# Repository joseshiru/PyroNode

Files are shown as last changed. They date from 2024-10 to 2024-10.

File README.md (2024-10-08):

# PyroNode

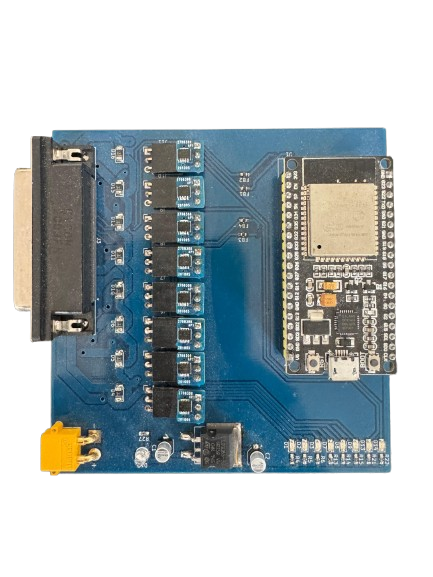
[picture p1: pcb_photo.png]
PCB Photo


**PyroNode** is an open-source ESP32-based control system designed to manage multiple outputs, monitor temperature, and provide robust control over external devices. Originally built for automotive applications as a cost-effective alternative to a PMU (Power Management Unit) or aftermarket ECU, PyroNode has proven its versatility and can be adapted for various other projects, such as home automation or even controlling a **coffee roaster**.

## Features

- **ESP32-based system**: Powerful microcontroller with Wi-Fi and Bluetooth capabilities.
- **8 MOSFET-controlled outputs**: Manage and control up to 8 high-power circuits.
- **Overload protection**: Ensures safety and reliability in high-power environments.
- **Temperature monitoring**: Supports 2 thermocouples via **MAX6675K** and other temperature sensors like **MAX31855EASA**.
- **Waterproof connectors**: Ideal for harsh environments such as automotive, outdoor, or industrial applications.
- **Optoisolated inputs**: Protects the system from electrical noise and interference.
- **Modular MOSFET satellites**: Easy expansion and replacement of MOSFET modules.
- **Flexible usage**: Designed initially for automotive use but adaptable to many applications, including industrial controls, environmental monitoring, or DIY home projects.

## Applications

While PyroNode was initially created for controlling circuits in an automotive environment (like a PMU without the expense of aftermarket systems), it can be utilized in a wide range of other scenarios:

- **Automotive**: Act as a PMU to control different car subsystems.
- **Home automation**: Manage lighting, HVAC, or any other electronic devices.
- **Coffee roasting**: Use the temperature sensors and output controls to monitor and adjust a coffee roaster in real-time.
- **Industrial automation**: Control machines and monitor temperature in industrial settings.
- **Smart gardening**: Automate watering systems and monitor environmental conditions.

## Project Breakdown

### Hardware Overview
- **MOSFET Modules**: Utilize **PSMN013-30MLC MOSFETs** for high-efficiency switching and control of the 8 output channels.
- **Power Supply**: Uses an **LD1085D2T33 voltage regulator** to provide a stable 3.3V power supply.
- **Temperature Monitoring**: Equipped with **2 thermocouples via MAX6675K** for accurate temperature measurements, expandable with additional sensors like the **MAX31855EASA**.
- **Waterproof Connectors**: For safe usage in outdoor or automotive applications.
- **Optoisolation**: Provides electrical isolation to protect the ESP32 from spikes or noise in the connected circuits.
- **Modular Design**: MOSFET satellite modules can be easily expanded or swapped for different configurations.

### Software Overview

The software is built using the **Arduino IDE** for the ESP32 platform. A basic example of controlling the MOSFETs is included in the `main.cpp` file. The example alternates turning on and off the 8 MOSFET outputs with a delay of 1 second.

```cpp
#include <Arduino.h>

int MOSFET0_PIN = 13;
int MOSFET1_PIN = 14;
int MOSFET2_PIN = 27;
int MOSFET3_PIN = 26;
int MOSFET4_PIN = 25;
int MOSFET5_PIN = 21;
int MOSFET6_PIN = 22;
int MOSFET7_PIN = 23;

void setup() {
  pinMode(MOSFET0_PIN, OUTPUT);
  pinMode(MOSFET1_PIN, OUTPUT);
  pinMode(MOSFET2_PIN, OUTPUT);
  pinMode(MOSFET3_PIN, OUTPUT);
  pinMode(MOSFET4_PIN, OUTPUT);
  pinMode(MOSFET5_PIN, OUTPUT);
  pinMode(MOSFET6_PIN, OUTPUT);
  pinMode(MOSFET7_PIN, OUTPUT);
}

void loop() {
  digitalWrite(MOSFET0_PIN, HIGH);
  digitalWrite(MOSFET1_PIN, HIGH);
  digitalWrite(MOSFET2_PIN, HIGH);
  digitalWrite(MOSFET3_PIN, HIGH);
  digitalWrite(MOSFET4_PIN, HIGH);
  digitalWrite(MOSFET5_PIN, HIGH);
  digitalWrite(MOSFET6_PIN, HIGH);
  digitalWrite(MOSFET7_PIN, HIGH);
  delay(1000);  
  digitalWrite(MOSFET0_PIN, LOW);
  digitalWrite(MOSFET1_PIN, LOW);
  digitalWrite(MOSFET2_PIN, LOW);
  digitalWrite(MOSFET3_PIN, LOW);
  digitalWrite(MOSFET4_PIN, LOW);
  digitalWrite(MOSFET5_PIN, LOW);
  digitalWrite(MOSFET6_PIN, LOW);
  digitalWrite(MOSFET7_PIN, LOW);
  delay(1000); 
}

```
## License

This project is licensed under the **Creative Commons Attribution-NonCommercial 4.0 International (CC BY-NC 4.0)** license.

- **Free for personal and non-commercial use.**
- **Credits: Build by Jose Zuniga Marin.**
- **For commercial use, please contact hello@malecu.eu.**

You can read the full license [here](https://creativecommons.org/licenses/by-nc/4.0/).

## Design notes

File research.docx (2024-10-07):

- MOSFETS
  - MOSFETs are more durable than relays. The price is comparable. The galvanic isolation rises a question [?].
  - The replaceability – a custom connector can be produced. The advantage is robustness and the possibility to sell dedicated MOSFET modules. The disadvantage is the additional price of the connector (and the satellite PCB). There are TO-220 connectors available, but they are expensive and does not seem to be durable.
  - MOSFET-based solution is much smaller:
    - 3.4 x 3.4 x 0.9 mm (MOSFET) + 23.1 x 15.4 x 7.3 mm (MR30PW connector ~2.5€/pair) OR 13.9 x 7.9 x 2.5 mm (angled goldpin connector ~0.2€/pair)
    - 28.5 x 27.2 x 24.8 mm (relay) + 27 x 25 x 20 mm (connector)
  - Possible solution(s):
    - PSMN013-30MLC
  - Using 25A MOSFETS might be an overkill [?] a bit. 25A*8=200A -> PCB and the connector can be unable to handle it.
- The connector
  - 2 power pins
  - 4 (2*2) thermocouple pins
  - 16 (8*2) relays/MOSFETs pins
  - Separate powers pins [?] (XT-60)
  - The expected current [?] must be taken into account.
  - Possible solution(s):
    - DSUB-25 (female, horizontal) – 3A
    - ECU (aliexpress) – expensive, 3-4A
- Voltage regulator
  - LD1085D2T33R (3A, 4.9-30V, D2PAK)

THE RESULTS

- ESP32 + needed passive elements
- MOSFETs -> PSMN013-30MLC (https://eu.mouser.com/ProductDetail/Nexperia/PSMN013-30MLC115?qs=qs9S9JrzwyZJD0ZHBCqfpw==)

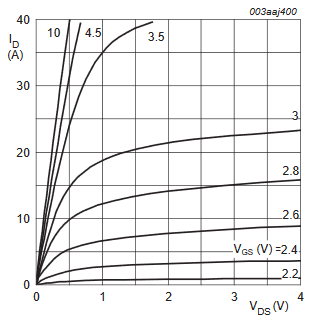
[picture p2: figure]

- Satellite boards for the MOSFETs
- LEDs to indicate MOSFETs states
- 8*2 MOSFET outputs + 2*2 thermocouple inputs
- The connector -> DSUB-25 (https://eu.mouser.com/ProductDetail/Amphenol-FCI/D25S23A4GV00LF?qs=V0y2QjpmBGS4pav1UJlQNQ%3D%3D) for signals + XT60PW-M (link (https://www.tme.eu/pl/details/xt60pw-m/zlacza-dc/amass/)) for power
- Voltage regulator -> LD1085D2T33R (link (https://www.tme.eu/pl/details/ld1085d2t33r/stabilizatory-napiecia-nieregulowane-ldo/stmicroelectronics/))

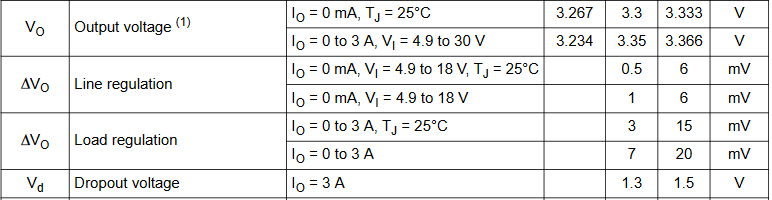
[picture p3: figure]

- Powering traces run parallelly on both PCB sides, unmasked, covered with solder

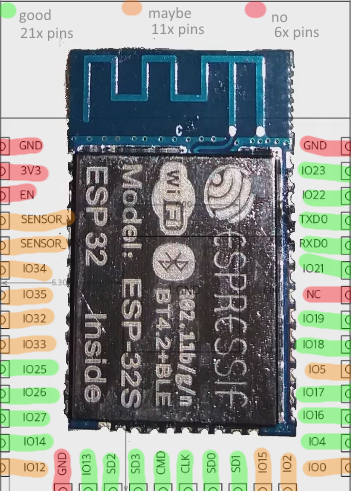
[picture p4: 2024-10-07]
image_2020_07_27T20_55_39_256Z.png

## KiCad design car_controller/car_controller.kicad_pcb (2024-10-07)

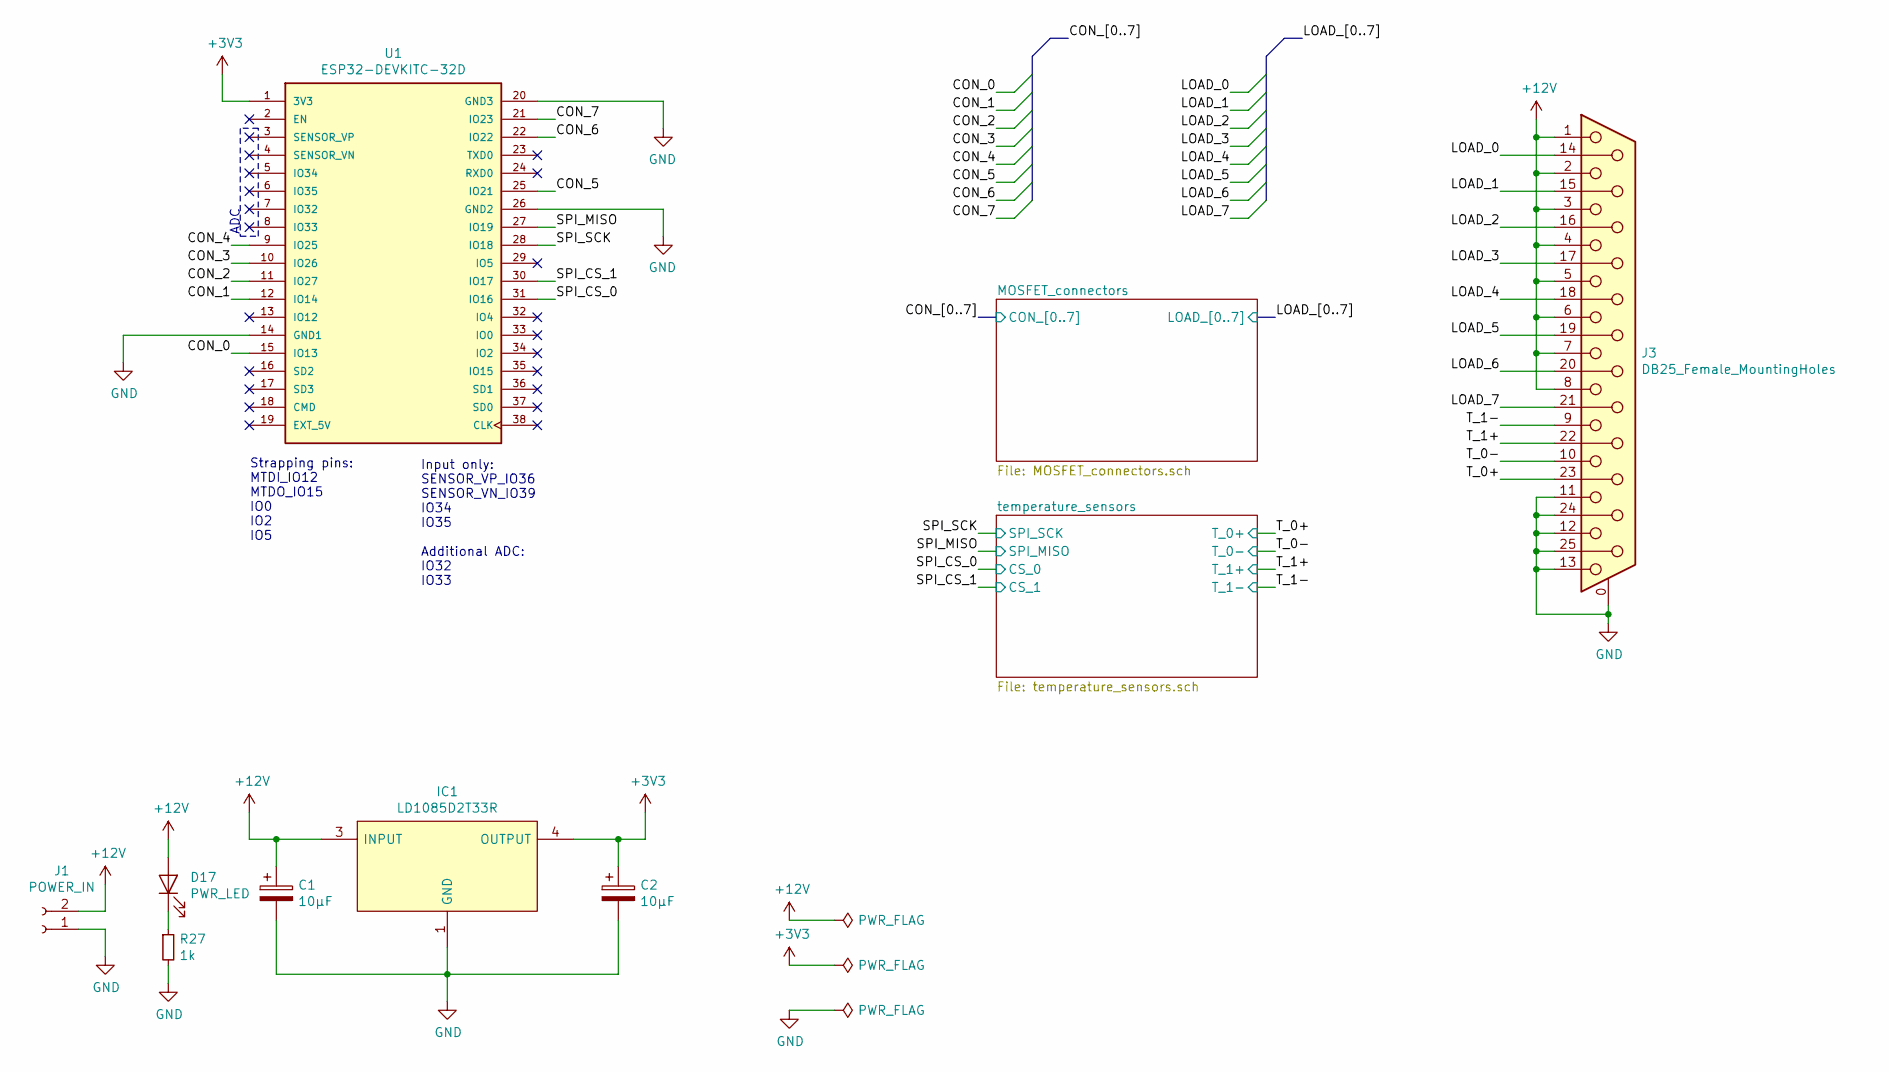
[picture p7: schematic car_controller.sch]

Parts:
C1, C2: 10µF; CP_Elec_4x5.3
D17: PWR_LED; LED_D3.0mm
IC1: LD1085D2T33R; Mouser Part Number 511-LD1085D2T33-TR
J1: POWER_IN; AMASS_XT30PW-M_1x02_P2.50mm_Horizontal
J3: DB25_Female_MountingHoles; DSUB-25_Female_Horizontal_P2.77x2.84mm_EdgePinOffset7.70mm_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
R27: 1k; R_0603_1608Metric_Pad1.05x0.95mm_HandSolder
U1: ESP32-DEVKITC-32D; MODULE_ESP32-DEVKITC-32D

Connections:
+3V3: C2.1, IC1.4 (OUTPUT), U1.1 (3V3); also elsewhere on the board
+12V: C1.1, D17.2 (A), IC1.3 (INPUT), J1.2, J3.1, J3.2, J3.3, J3.4, J3.5, J3.6, J3.7, J3.8; also elsewhere on the board
/CON_0: U1.15 (IO13); also elsewhere on the board
/CON_1: U1.12 (IO14); also elsewhere on the board
/CON_2: U1.11 (IO27); also elsewhere on the board
/CON_3: U1.10 (IO26); also elsewhere on the board
/CON_4: U1.9 (IO25); also elsewhere on the board
/CON_5: U1.25 (IO21); also elsewhere on the board
/CON_6: U1.22 (IO22); also elsewhere on the board
/CON_7: U1.21 (IO23); also elsewhere on the board
/LOAD_0: J3.14; also elsewhere on the board
/LOAD_1: J3.15; also elsewhere on the board
/LOAD_2: J3.16; also elsewhere on the board
/LOAD_3: J3.17; also elsewhere on the board
/LOAD_4: J3.18; also elsewhere on the board
/LOAD_5: J3.19; also elsewhere on the board
/LOAD_6: J3.20; also elsewhere on the board
/LOAD_7: J3.21; also elsewhere on the board
/SPI_CS_0: U1.31 (IO16); also elsewhere on the board
/SPI_CS_1: U1.30 (IO17); also elsewhere on the board
/SPI_MISO: U1.27 (IO19); also elsewhere on the board
/SPI_SCK: U1.28 (IO18); also elsewhere on the board
/T_0+: J3.23; also elsewhere on the board
/T_0-: J3.10; also elsewhere on the board
/T_1+: J3.22; also elsewhere on the board
/T_1-: J3.9; also elsewhere on the board
GND: C1.2, C2.2, IC1.1 (GND), J1.1, J3.0 (PAD), J3.11, J3.12, J3.13, J3.24, J3.25, R27.2, U1.14 (GND1), U1.20 (GND3), U1.26 (GND2); also elsewhere on the board
unnamed: D17.1 (K), R27.1

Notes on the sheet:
Strapping pins: MTDI_IO12 MTDO_IO15 IO0 IO2 IO5
Input only: SENSOR_VP_IO36 SENSOR_VN_IO39 IO34 IO35 Additional ADC: IO32 IO33
ADC

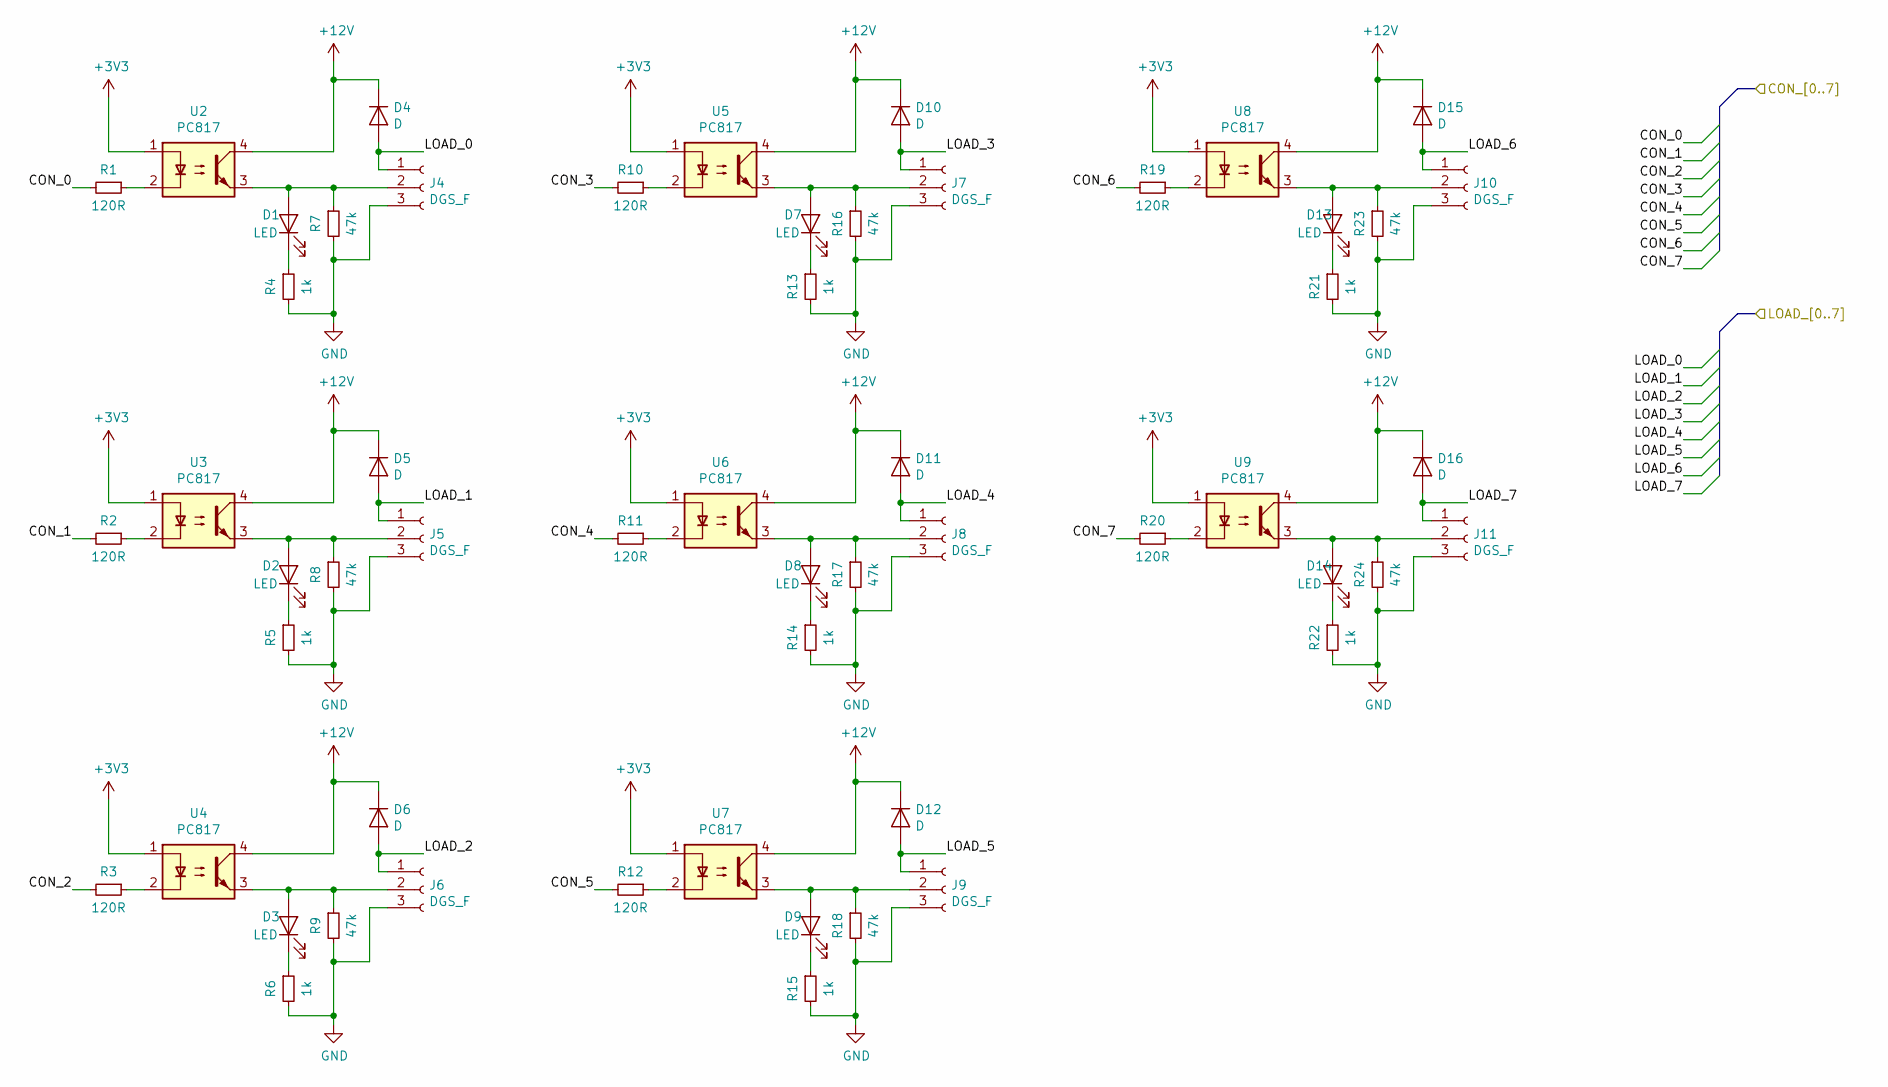
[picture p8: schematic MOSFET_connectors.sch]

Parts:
D1, D2, D3, D7, D8, D9, D13, D14: LED; LED_0805_2012Metric_Pad1.15x1.40mm_HandSolder
D4, D5, D6, D10, D11, D12, D15, D16: D; D_1206_3216Metric_Pad1.42x1.75mm_HandSolder
J4, J5, J6, J7, J8, J9, J10, J11: DGS_F; PinSocket_1x03_P2.54mm_Horizontal
R1, R2, R3, R10, R11, R12, R19, R20: 120R; R_0603_1608Metric_Pad1.05x0.95mm_HandSolder
R4, R5, R6, R13, R14, R15, R21, R22: 1k; R_0603_1608Metric_Pad1.05x0.95mm_HandSolder
R7, R8, R9, R16, R17, R18, R23, R24: 47k; R_0603_1608Metric_Pad1.05x0.95mm_HandSolder
U2, U3, U4, U5, U6, U7, U8, U9: PC817; OPTO-SMD4

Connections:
+3V3: U2.1, U3.1, U4.1, U5.1, U6.1, U7.1, U8.1, U9.1; also elsewhere on the board
+12V: D4.1 (K), D5.1 (K), D6.1 (K), D10.1 (K), D11.1 (K), D12.1 (K), D15.1 (K), D16.1 (K), U2.4, U3.4, U4.4, U5.4, U6.4, U7.4, U8.4, U9.4; also elsewhere on the board
/CON_0: R1.2; also elsewhere on the board
/CON_1: R2.2; also elsewhere on the board
/CON_2: R3.2; also elsewhere on the board
/CON_3: R10.2; also elsewhere on the board
/CON_4: R11.2; also elsewhere on the board
/CON_5: R12.2; also elsewhere on the board
/CON_6: R19.2; also elsewhere on the board
/CON_7: R20.2; also elsewhere on the board
/LOAD_0: D4.2 (A), J4.1; also elsewhere on the board
/LOAD_1: D5.2 (A), J5.1; also elsewhere on the board
/LOAD_2: D6.2 (A), J6.1; also elsewhere on the board
/LOAD_3: D10.2 (A), J7.1; also elsewhere on the board
/LOAD_4: D11.2 (A), J8.1; also elsewhere on the board
/LOAD_5: D12.2 (A), J9.1; also elsewhere on the board
/LOAD_6: D15.2 (A), J10.1; also elsewhere on the board
/LOAD_7: D16.2 (A), J11.1; also elsewhere on the board
GND: J4.3, J5.3, J6.3, J7.3, J8.3, J9.3, J10.3, J11.3, R4.2, R5.2, R6.2, R7.2, R8.2, R9.2, R13.2, R14.2, R15.2, R16.2, R17.2, R18.2, R21.2, R22.2, R23.2, R24.2; also elsewhere on the board
unnamed: D1.1 (K), R4.1
unnamed: D1.2 (A), J4.2, R7.1, U2.3
unnamed: D2.1 (K), R5.1
unnamed: D2.2 (A), J5.2, R8.1, U3.3
unnamed: D3.1 (K), R6.1
unnamed: D3.2 (A), J6.2, R9.1, U4.3
unnamed: D7.1 (K), R13.1
unnamed: D7.2 (A), J7.2, R16.1, U5.3
unnamed: D8.1 (K), R14.1
unnamed: D8.2 (A), J8.2, R17.1, U6.3
unnamed: D9.1 (K), R15.1
unnamed: D9.2 (A), J9.2, R18.1, U7.3
unnamed: D13.1 (K), R21.1
unnamed: D13.2 (A), J10.2, R23.1, U8.3
unnamed: D14.1 (K), R22.1
unnamed: D14.2 (A), J11.2, R24.1, U9.3
unnamed: R1.1, U2.2
unnamed: R2.1, U3.2
unnamed: R3.1, U4.2
unnamed: R10.1, U5.2
unnamed: R11.1, U6.2
unnamed: R12.1, U7.2
unnamed: R19.1, U8.2
unnamed: R20.1, U9.2

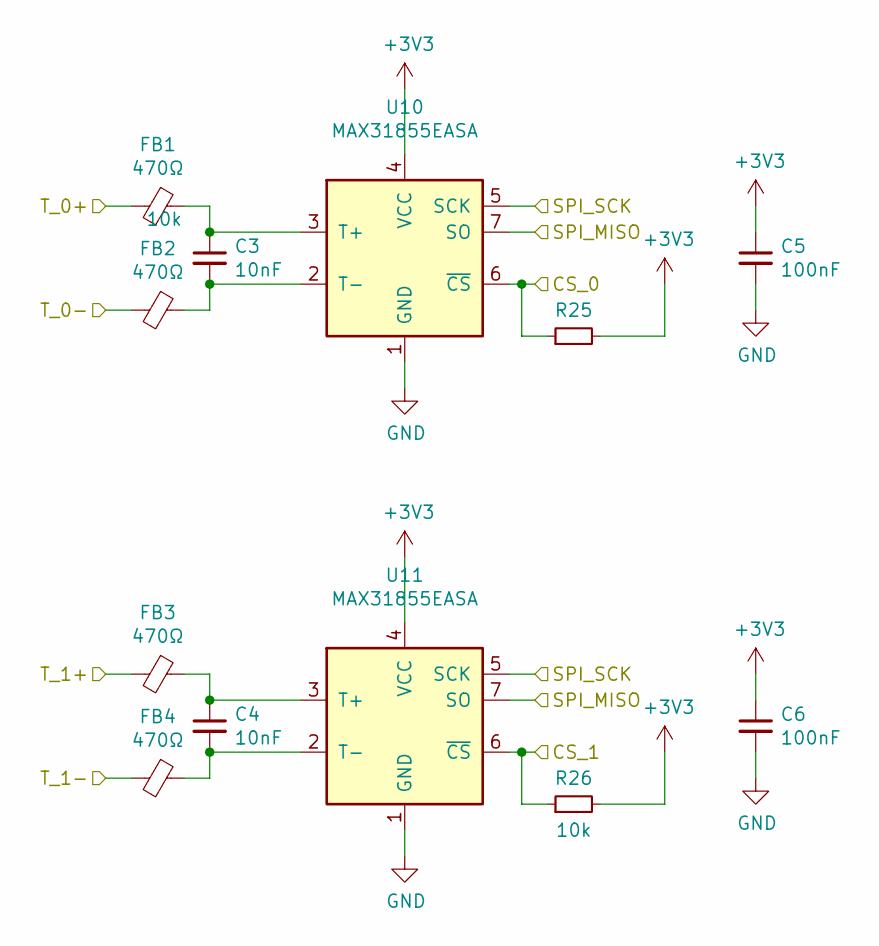
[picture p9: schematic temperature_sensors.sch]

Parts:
C3, C4: 10nF; C_0603_1608Metric
C5, C6: 100nF; C_0603_1608Metric
FB1, FB2, FB3, FB4: 470Ω; L_0603_1608Metric_Pad1.05x0.95mm_HandSolder
R25, R26: 10k; R_0603_1608Metric_Pad1.05x0.95mm_HandSolder
U10, U11: MAX31855EASA; SOIC-8_3.9x4.9mm_P1.27mm

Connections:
+3V3: C5.1, C6.1, R25.2, R26.2, U10.4 (VCC), U11.4 (VCC); also elsewhere on the board
/SPI_CS_0: R25.1, U10.6 (~CS~); also elsewhere on the board
/SPI_CS_1: R26.1, U11.6 (~CS~); also elsewhere on the board
/SPI_MISO: U10.7 (SO), U11.7 (SO); also elsewhere on the board
/SPI_SCK: U10.5 (SCK), U11.5 (SCK); also elsewhere on the board
/T_0+: FB1.2; also elsewhere on the board
/T_0-: FB2.2; also elsewhere on the board
/T_1+: FB3.2; also elsewhere on the board
/T_1-: FB4.2; also elsewhere on the board
GND: C5.2, C6.2, U10.1 (GND), U11.1 (GND); also elsewhere on the board
unnamed: C3.1, FB1.1, U10.3 (T+)
unnamed: C3.2, FB2.1, U10.2 (T-)
unnamed: C4.1, FB3.1, U11.3 (T+)
unnamed: C4.2, FB4.1, U11.2 (T-)

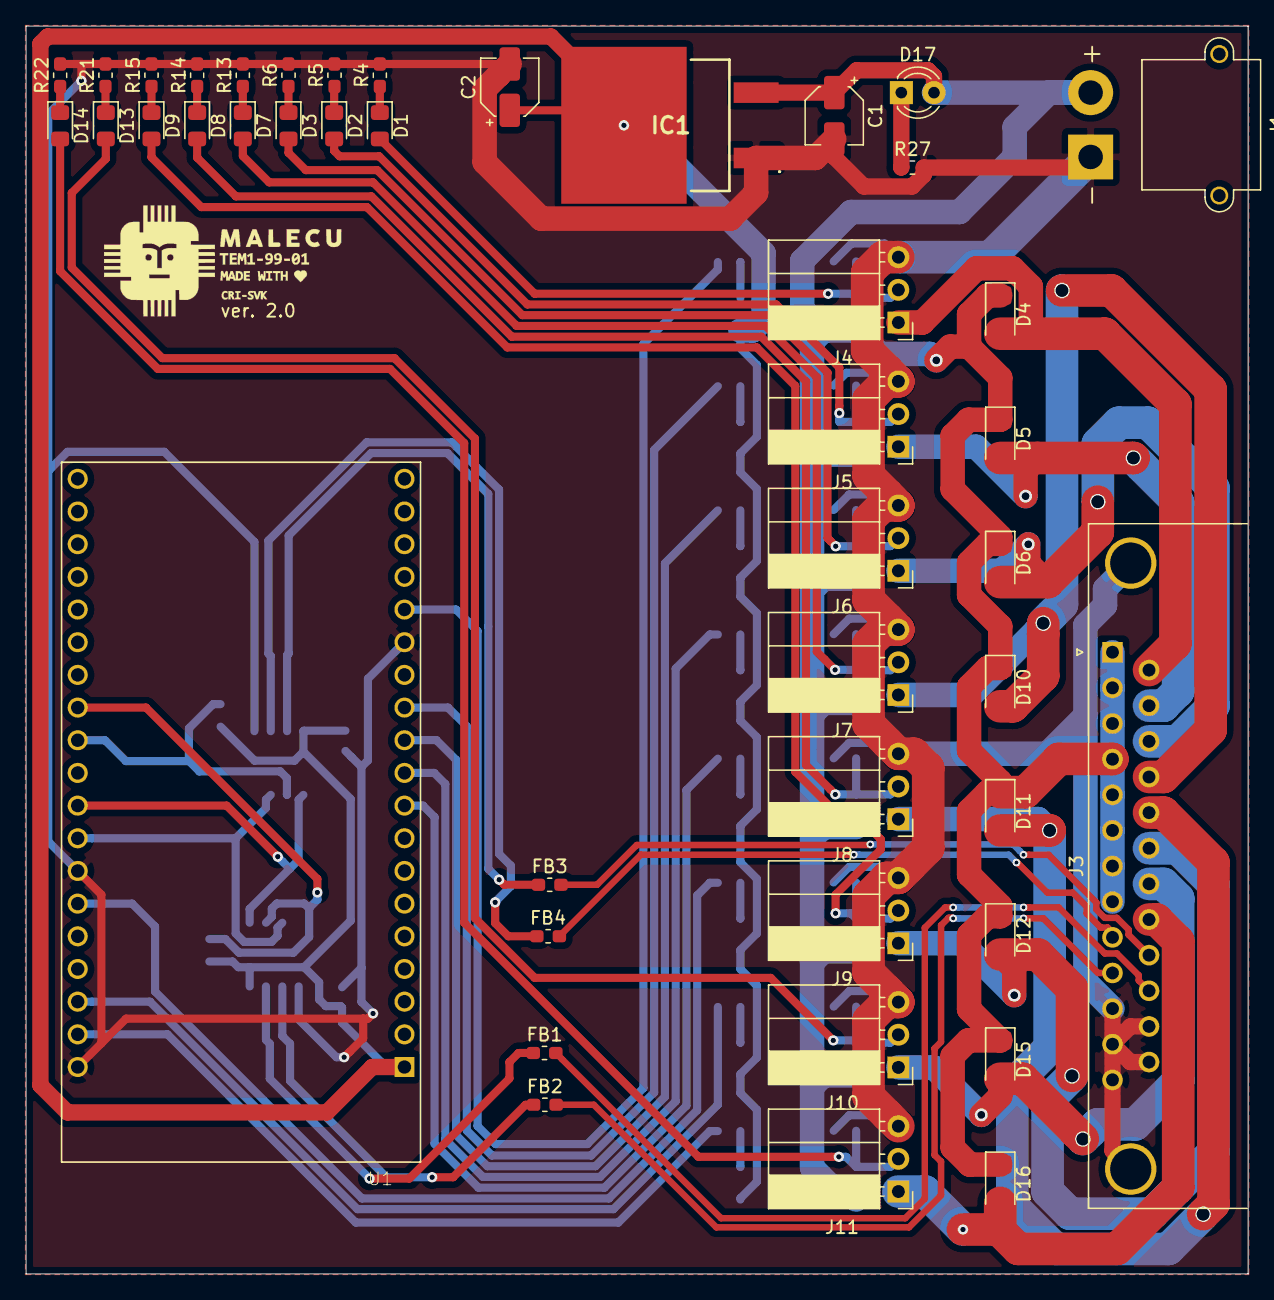
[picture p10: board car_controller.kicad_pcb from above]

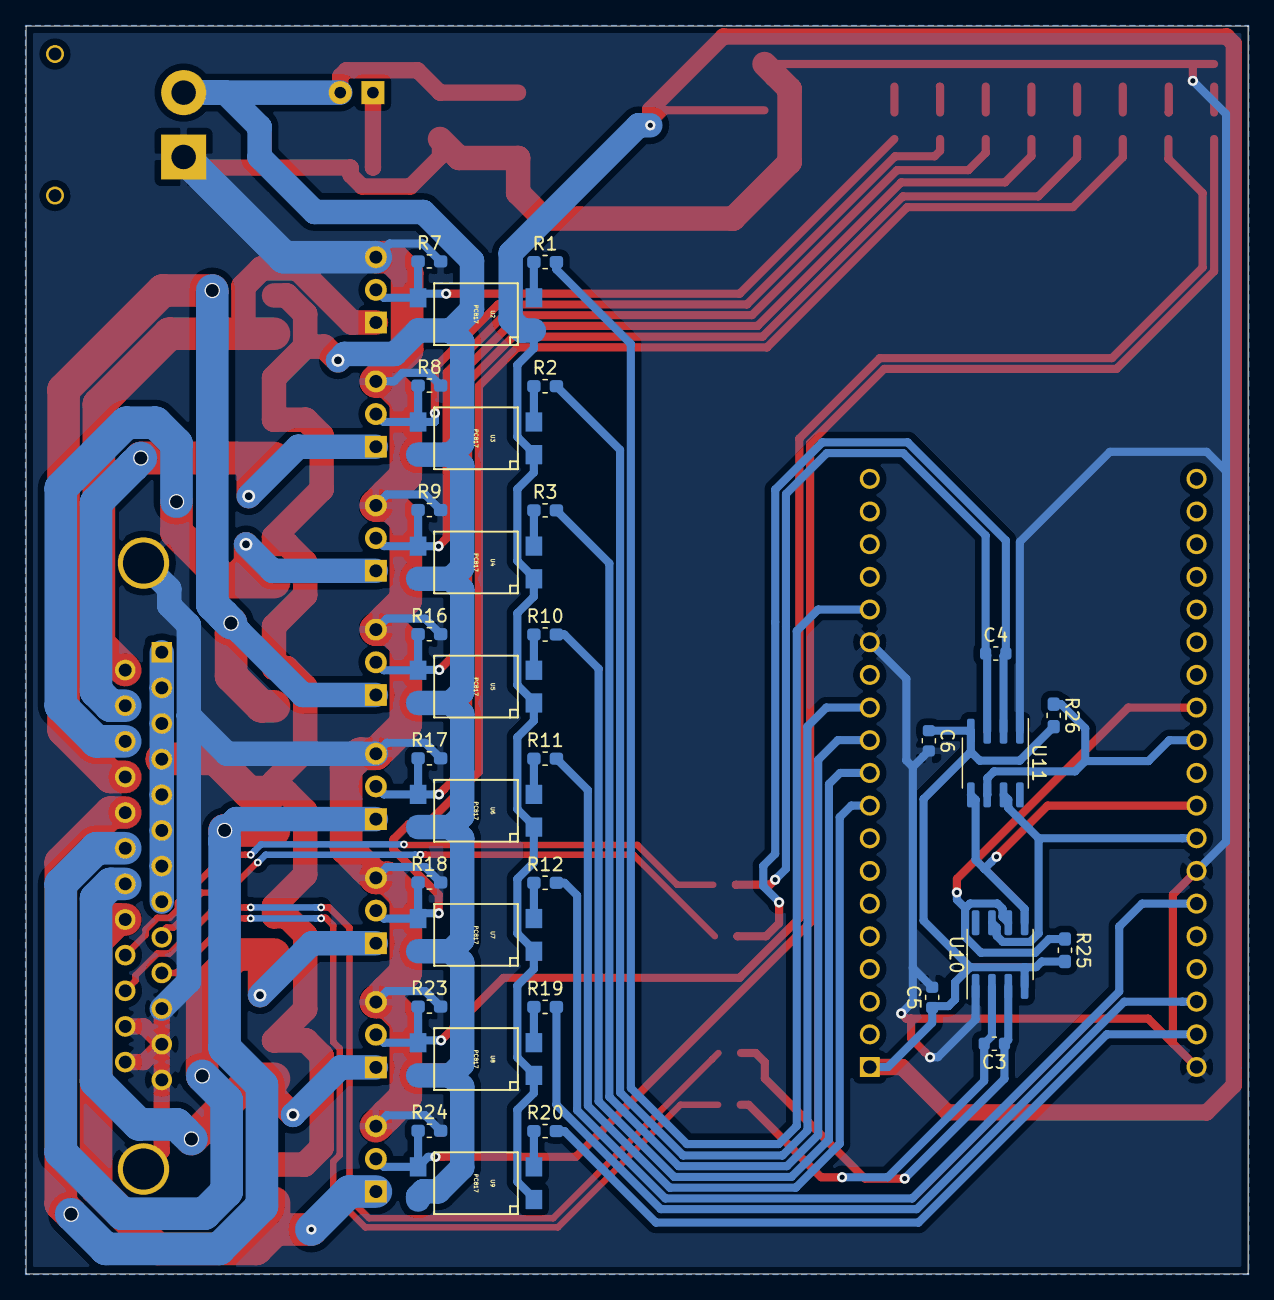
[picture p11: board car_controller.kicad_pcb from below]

Board: 2 copper layers, 95.0 x 97.0 mm, 76 parts (32 on the bottom side), 56 nets.

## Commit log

2024-10-08 Update contact email. Add PCB photo
2024-10-08 Add PCB image to Readme file
